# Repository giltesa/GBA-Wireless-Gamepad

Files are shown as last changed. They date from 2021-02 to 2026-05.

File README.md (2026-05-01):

# Game Boy Advance: Bluetooth HID Gamepad

### DESCRIPTION
This simple circuit allows you to connect an **ESP32** to the Link Cable port of the **Game Boy Advance** or **Game Boy Advance SP**, giving it **bluetooth** connectivity and turning it into a Human Interface Device (**HID**) so it can be used as a **bluetooth gamepad** and connected to a computer or phone to control games from the GBA.

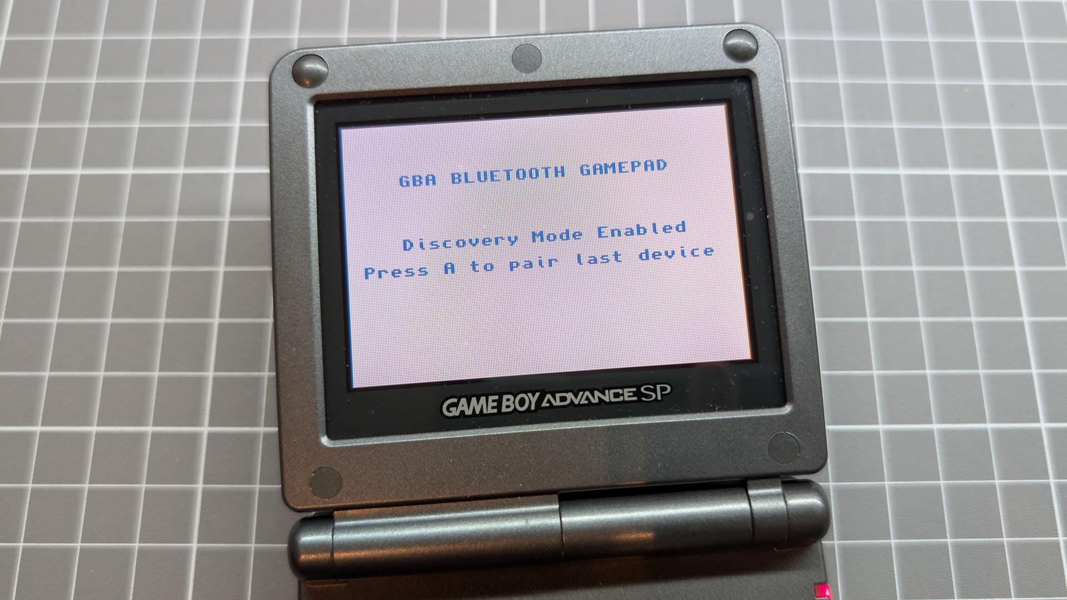
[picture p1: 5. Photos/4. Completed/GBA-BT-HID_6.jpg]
GBA-BT-HID_6


### REQUIRED
*   1x Game Boy Advance Wireless Adapter (shell & connector)
*   1x PCB (Download the Gerber files and order it yourself, PCB Thickness: 1mm)
*   1x ESP-WROOM-32 ESP32-WROOM-NARROW
*   1x Resistor 0603 1K
*   2x Resistor 0603 10K
*   1x LED 0603
*   2x Switch bottom 4.6\*2.8mm
*   1x USB UART-CP2102 **(1)**

**(1)** This [USB UART adapter](https://www.aliexpress.com/item/1005009534233685.html) can be connected directly to the board without the need for cables or soldering. Just connect it and keep both boards at a 45-degree angle so all the pins make electrical contact. Hold them together with a rubber band and, after programming the code, disconnect the boards.

### NOTES
I had a lot of difficulties in 2020 trying to flash the code onto the ESP32, and I eventually gave up without succeeding. Now, in 2026, I gave it another try and finally managed to do it, but it is still quite complicated for anyone not familiar with ESP32 development tools.

**Shyri Villar**’s code needs to be compiled to generate the .bin file, and once you have it, it must be flashed onto the ESP32. To simplify the process, I uploaded the already compiled .bin file to my repository, so the only remaining step is flashing it onto the ESP32. I also uploaded instructions to help with that task.

### ATTRIBUTIONS
The original idea is not mine, but [**Shyri Villar**](https://github.com/Shyri)’s, who designed it for a GBA to NGC cable and developed the software. I only adapted it to work with the GBA wireless adapter.

### LICENSE
This project is licensed under a **Creative Commons** license:
**[Attribution-NonCommercial-ShareAlike 4.0 International (CC BY-NC-SA 4.0) ](https://creativecommons.org/licenses/by-nc-sa/4.0/)**

Check the [LICENSE.md](LICENSE.md) for more information.

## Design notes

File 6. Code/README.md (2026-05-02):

# Flashing the ESP32 Firmware

This project includes precompiled ESP32 firmware binaries, so you do **not** need to compile anything yourself.

# Requirements

## Hardware

- ESP32 board
- USB cable
- Windows PC

## Files included

```text
flash_esp32.bat
bootloader.bin
gba-bt-hid-fw-esp32.bin
partitions_singleapp.bin
```

---

# Method 1 (Recommended) — Automatic Flash Tool

This is the easiest method.

## Step 1 — Install Python

Download and install Python:

https://www.python.org/downloads/windows/

IMPORTANT:

During installation, enable:

```text
Add Python to PATH
```

---

## Step 2 — Install esptool

Open PowerShell and run:

```powershell
py -m pip install esptool
```

---

## Step 3 — Connect the ESP32

Connect the ESP32 board to your PC using USB.

Wait a few seconds for Windows to detect it.

---

## Step 4 — Run the Flash Tool

Open the folder:

```text
6. Code
```

Double-click:

```text
flash_esp32.bat
```

The tool will display available COM ports, for example:

```text
Available COM ports:

  [1] COM3 - Silicon Labs CP210x USB to UART Bridge
  [2] COM5 - USB Serial Device
```

Type the number corresponding to your ESP32 and press ENTER.

Example:

```text
1
```

The firmware will then be flashed automatically.

---

# Method 2 — Manual Flashing

If the batch file does not work, you can flash manually.

Open PowerShell inside the `6. Code` folder and run:

```powershell
py -m esptool --chip esp32 --port COM3 --baud 115200 write_flash -z ^
0x1000 bootloader.bin ^
0x8000 partitions_singleapp.bin ^
0x10000 gba-bt-hid-fw-esp32.bin
```

Replace:

```text
COM3
```

with your actual ESP32 COM port.

---

# How to Find the Correct COM Port

## Option 1 — Device Manager

Open:

```text
Device Manager → Ports (COM & LPT)
```

Example:

```text
Silicon Labs CP210x USB to UART Bridge (COM3)
```

Your port is:

```text
COM3
```

---

# Flash Successful

If flashing completes correctly, you should see:

```text
Hash of data verified.
Leaving...
Hard resetting via RTS pin...
```

The ESP32 firmware is now installed and ready to use.

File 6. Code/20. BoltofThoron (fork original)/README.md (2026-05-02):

## GBA as Bluetooth Gamepad ##
Turn your Game Boy Advance into a Bluetooth Controller :)
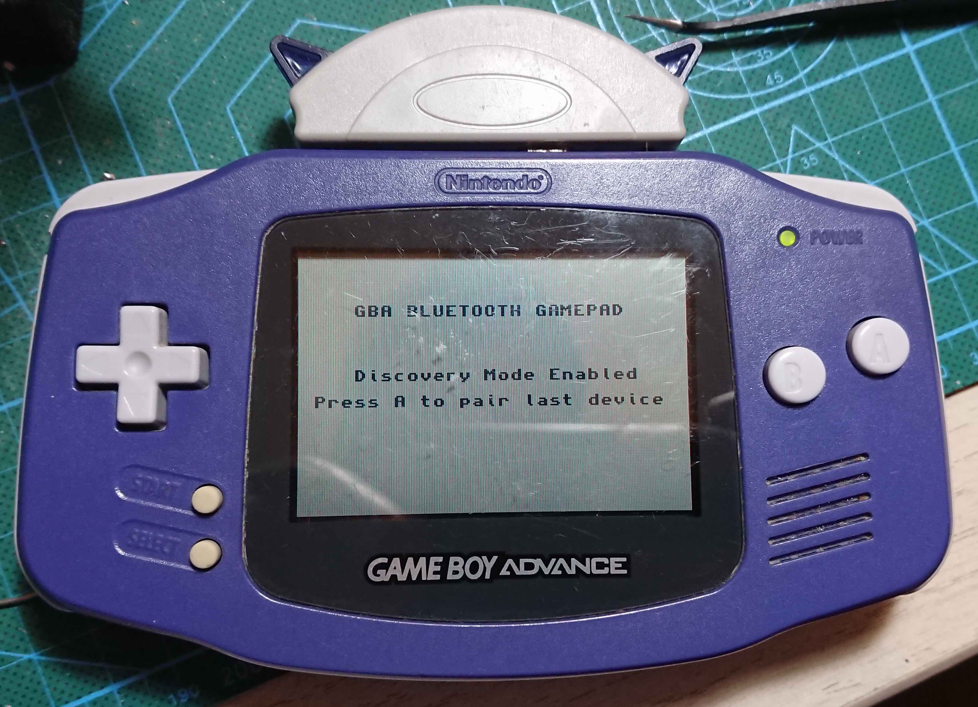
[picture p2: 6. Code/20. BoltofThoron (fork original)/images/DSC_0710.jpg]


### How to use it: ###
After launching the rom the bluetooth module enters discoverable mode. This means you can pair to it from whatever device you are going to use it with (PC, phone, Android TV...). After pairing the program will start sending keys to the device. The device address is stored so next time you launch you just have to press A to automatically connect to that device.

### How it works: ###
The project is basically an ESP32 connected to the GBA through the link port. With the device connected and without any cartridge inserted in the GBA, once the GBA turns on the ESP32 sends a small rom to be loaded in the GBA. This rom is a program made to enable communication between the ESP32 and GBA for both handling bluetooth conneciton and sending the user input to the ESP32 when it is connected to a bluetooth host and act as a gamepad. Unfortunatelly it only works with traditional GBA as I couln't make it work with GBA SP. This project supports the AGB-001 GBA, AGS-101 GBA SP, and DOL-017 GameCube Game Boy Player models. The AGS-001 GBA SP and OXY-001 Game Boy Micro are untested but should also work (Micro will require an EXT adapter).

When turned on the ESP32 (using the code found in [esp32](esp32) peforms a multiboot sequence through the SPI to the GBA sending a rom that the ESP32 has stored in the flash memory. The code for this rom can be found in [gba](gba). Once loaded the ESP32 enables the UART port in the same pins and the rom communicates with the ESP32 using UART through the link port.

This project was tested with ESP-IDF v3.3.2 that you can find here:

https://github.com/espressif/esp-idf/releases

You also will need to install btstack. Commit https://github.com/bluekitchen/btstack/commit/a0a4507b35ea396d076a62a67efb1a5a800c5ff9 is the most recent version that is proved to work in this project.

Just follow the ESP32 environment instructions here: https://docs.espressif.com/projects/esp-idf/en/v3.3.2/get-started/index.html

The ESP32 is powered by the 3.3V the GBA gives through the port.
Once the ESP32 is programmed the male link port connector should be wired to it like the following diagram:
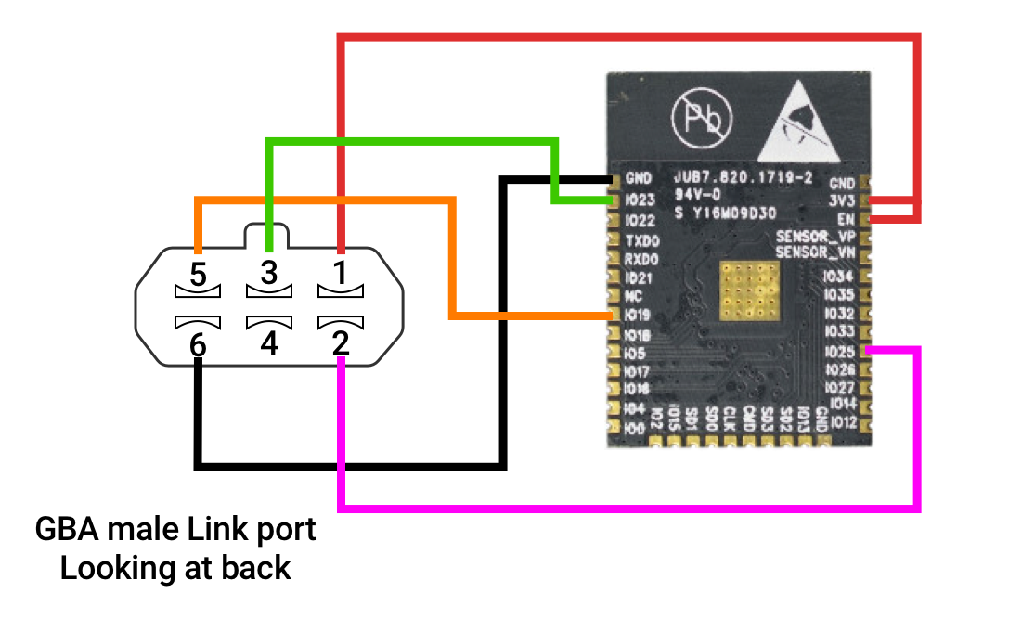
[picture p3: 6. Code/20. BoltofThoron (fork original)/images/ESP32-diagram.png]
ESP32Diagram Diagram


The first prototype was made with an Atmega and HC-05:
### Old version prototype: ###
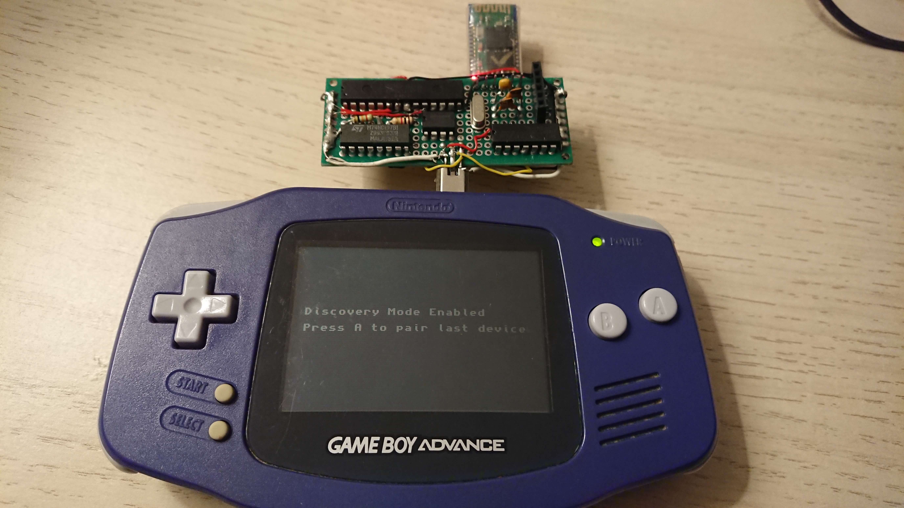
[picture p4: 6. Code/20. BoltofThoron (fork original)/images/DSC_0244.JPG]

The [gba](gba) contains the code for a GBA program that uses the link port to communicate with a HC-05 bluetooth module using UART (HC-05 flashed with RN-42 firmware, find how to do it in the links at the bottom).

This rom is stored in a W25Q32 flash chip. An Atmega328P performs a multiboot sequence reading from this chip and sending to the GBA through the link port. You can find the Atmega code [here](arduino) (It is actually written for arduino so you'll need to burn arduino's bootloader if you want to use it).

Once multiboot ends, the gba program runs and talks to the HC-05 to handle bluetooth connection, and key presses.

Additional 74XX157 quad 2-input multiplexer makes possible to multiplex SPI to read from the flash chip and send the multiboot, it alternates byte reads from the flash chip and send them to the GBA. Then using hcf4066 switch link port pins are switched from the spi to the HC-05 uart pins.

The whole circuit runs at 3.3V provided by GBA through the link port.

Final version of the circuit includes a 6 pin port that allows to reprogram the atmega if necessary. Also it lets to turn the atmega into a special write mode to reprogram the flash memory. You can find the code for the memory programmer [here](arduino-rom-flasher) it needs to run in a separate board (not arduino due to the large size of the rom to program, I used a Stellaris Launchpad)

There's a KiCad project [here](circuit) that includes this diagram:
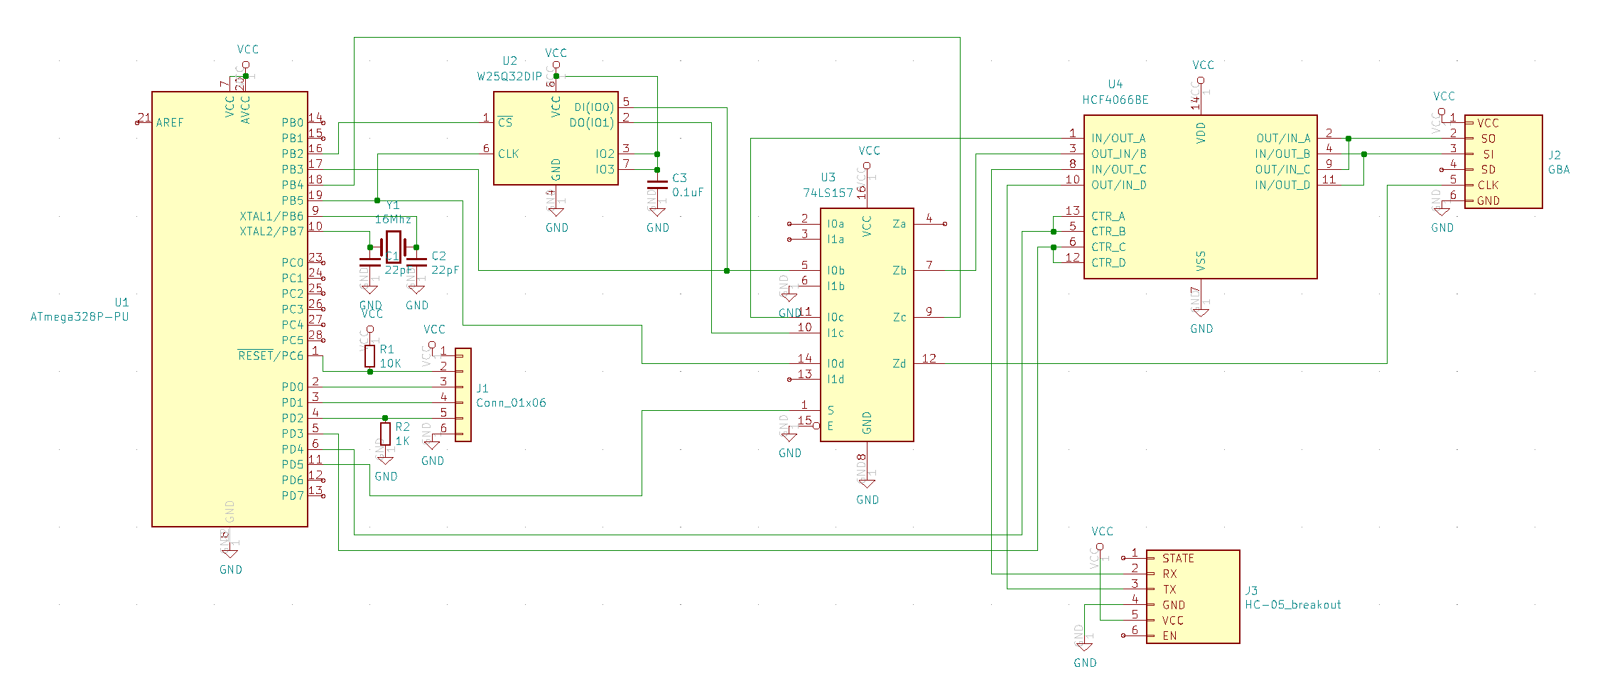
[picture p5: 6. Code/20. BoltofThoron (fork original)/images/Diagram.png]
Diagram GBA


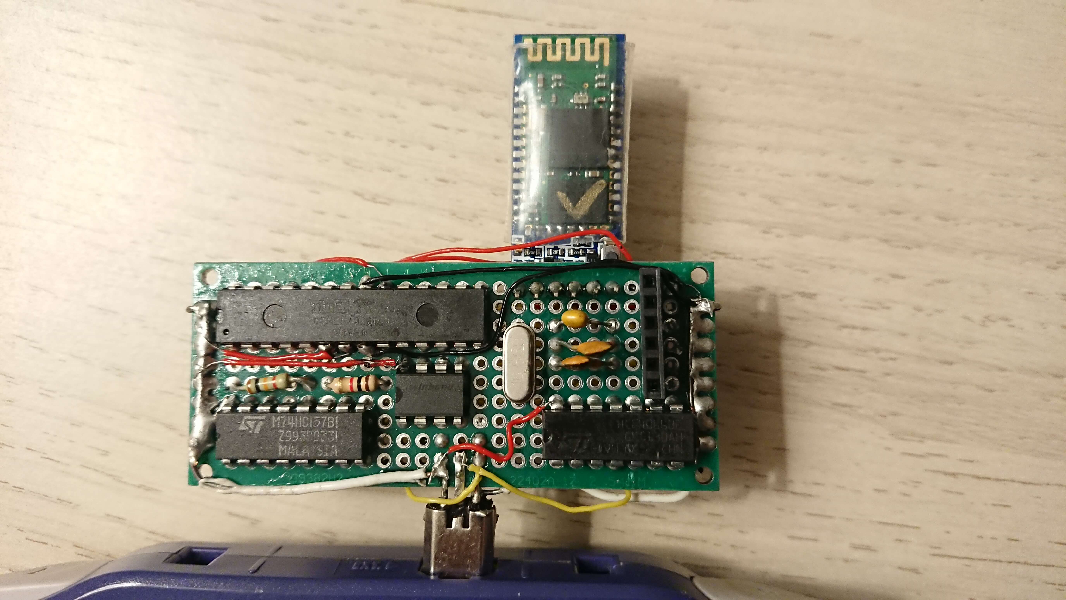
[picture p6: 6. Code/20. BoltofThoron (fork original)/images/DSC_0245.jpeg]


### Links that helped me to get this done: ###
ESP32 as a bluetooth Gamepad:
Thanks to the Bluecubemod from Nathan Reeves I learned how to turn ESP32 into a bluetooth gamepad
https://github.com/NathanReeves/BlueCubeMod

HC-05 as bluetooth HID device:

https://www.youtube.com/watch?v=y8PcNbAA6AQ

https://www.youtube.com/watch?v=BBqsVKMYz1I

GBA Multiboot:

http://www.akkit.org/info/gbatek.htm

https://github.com/akkera102/gba_01_multiboot

https://github.com/ataulien/elm-gba-multiboot

https://github.com/cartr/MSMCcable

https://github.com/tangrs/usb-gba-multiboot

https://github.com/MerryMage/gba-multiboot

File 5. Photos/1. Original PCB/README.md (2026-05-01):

# Original PCB

This section shows the original Nintendo Game Boy Advance wireless controller PCB design.

These images are provided for reference and documentation purposes.

## Gallery

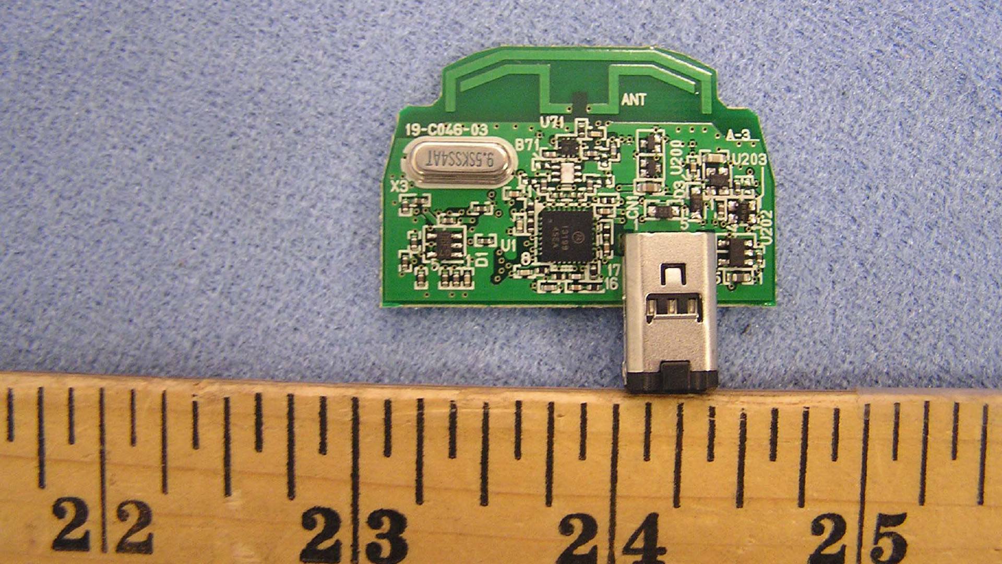
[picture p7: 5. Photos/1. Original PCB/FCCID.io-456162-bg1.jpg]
FCCID.io-456162-bg1

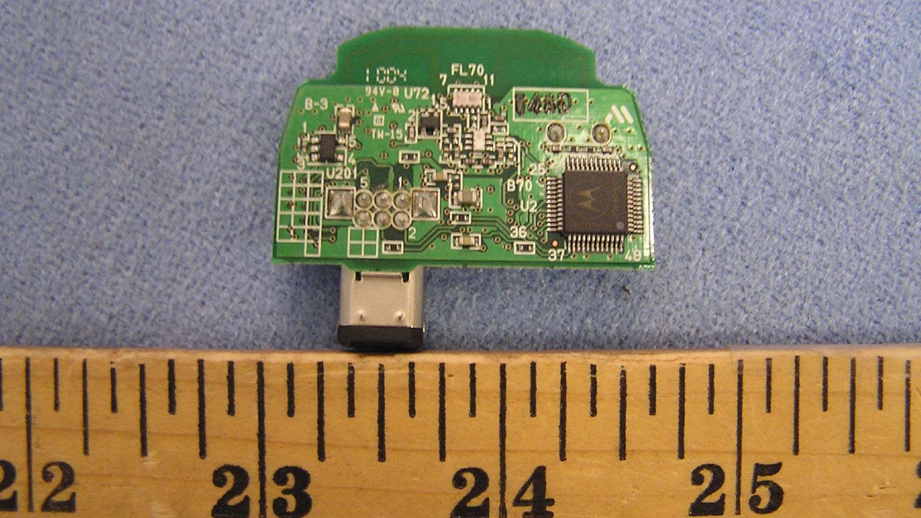
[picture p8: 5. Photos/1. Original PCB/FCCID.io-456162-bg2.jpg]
FCCID.io-456162-bg2

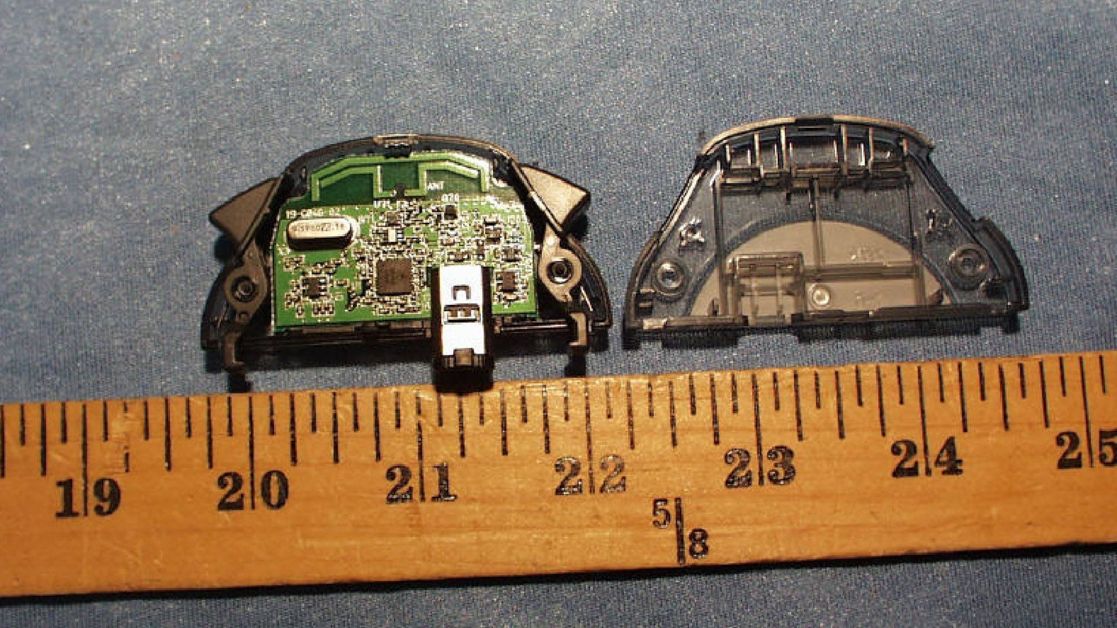
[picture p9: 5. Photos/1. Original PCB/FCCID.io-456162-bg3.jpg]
FCCID.io-456162-bg3

P1170439
P1170443
P1170444

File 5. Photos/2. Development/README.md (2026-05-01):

# Development

This section shows images from the development process of the GBA Wireless Gamepad PCB.

These photos document different stages of prototyping, and testing.

## Gallery



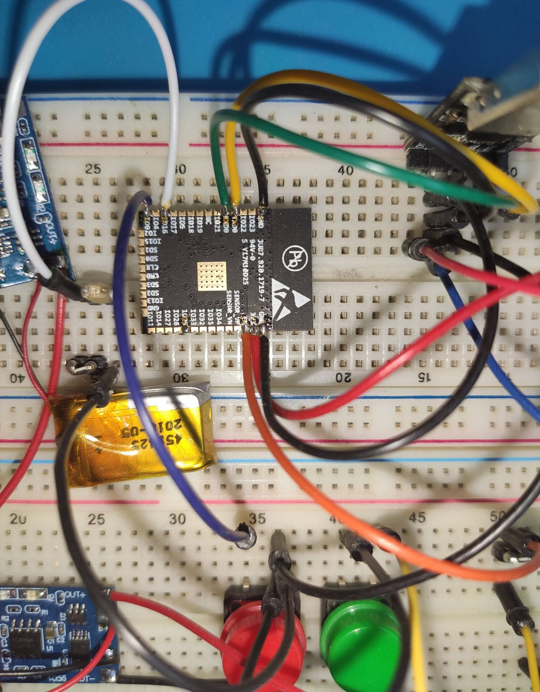
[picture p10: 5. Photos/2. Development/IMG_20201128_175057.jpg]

P1170456
P1170457
P1170461

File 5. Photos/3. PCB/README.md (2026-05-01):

# PCB (Assembled Board)

This section shows the manufactured and fully assembled PCB of the GBA Wireless Gamepad.

These images document the final hardware build, including soldering and component placement.

## Gallery

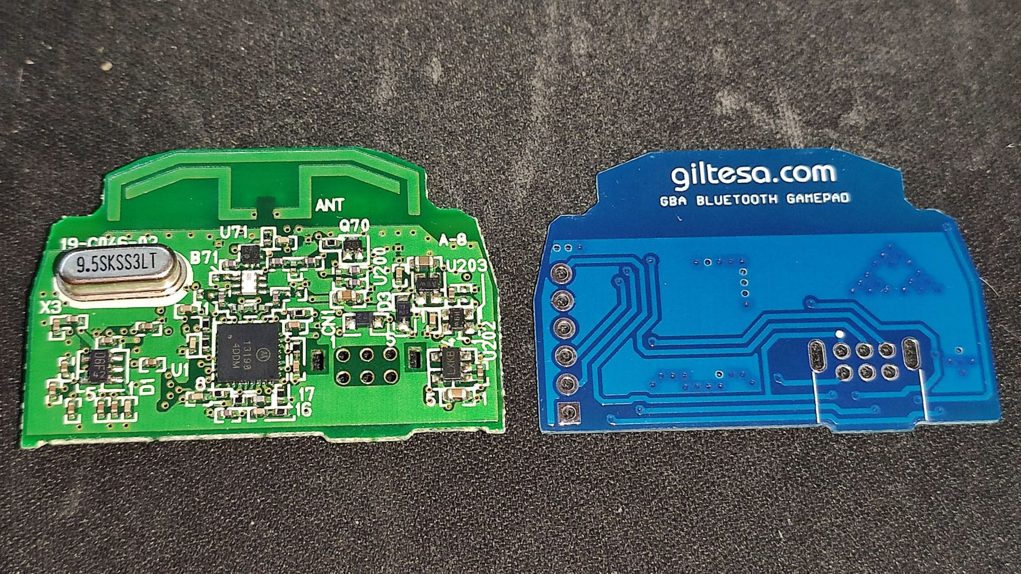
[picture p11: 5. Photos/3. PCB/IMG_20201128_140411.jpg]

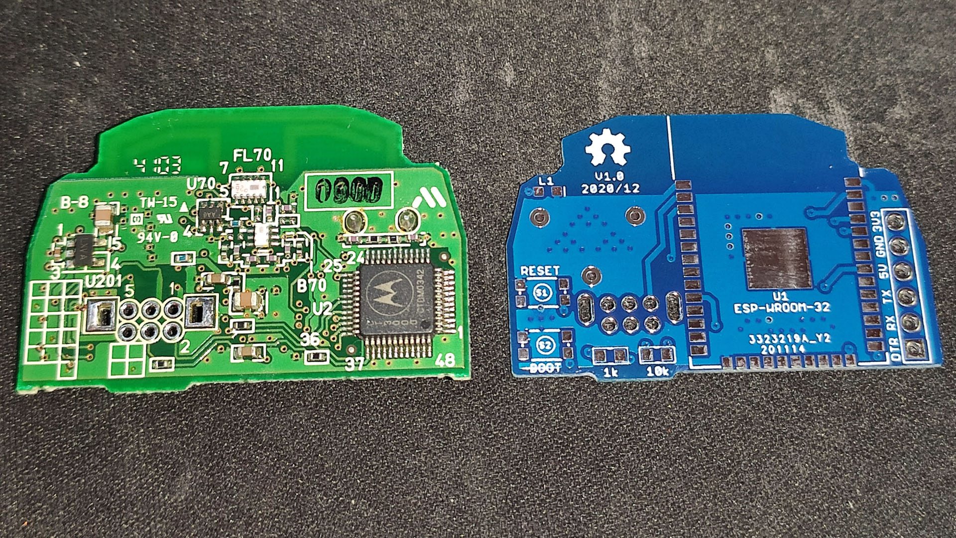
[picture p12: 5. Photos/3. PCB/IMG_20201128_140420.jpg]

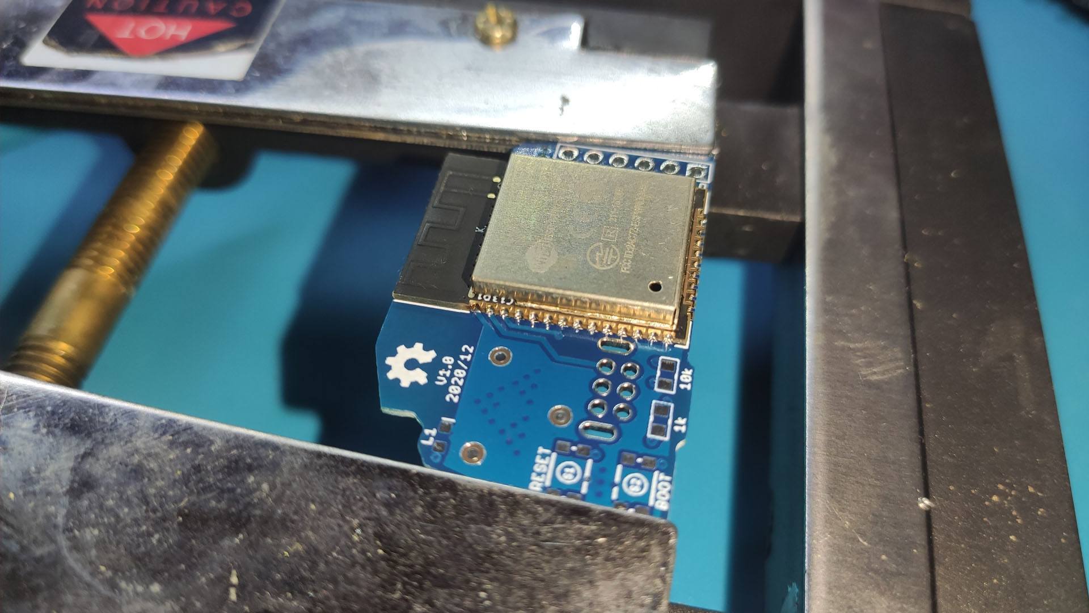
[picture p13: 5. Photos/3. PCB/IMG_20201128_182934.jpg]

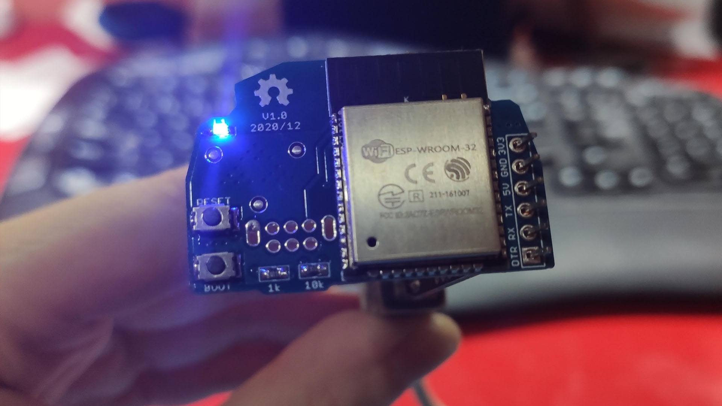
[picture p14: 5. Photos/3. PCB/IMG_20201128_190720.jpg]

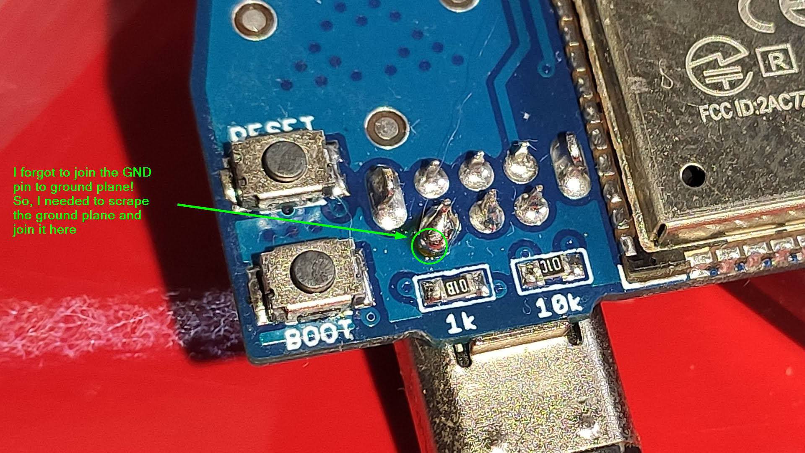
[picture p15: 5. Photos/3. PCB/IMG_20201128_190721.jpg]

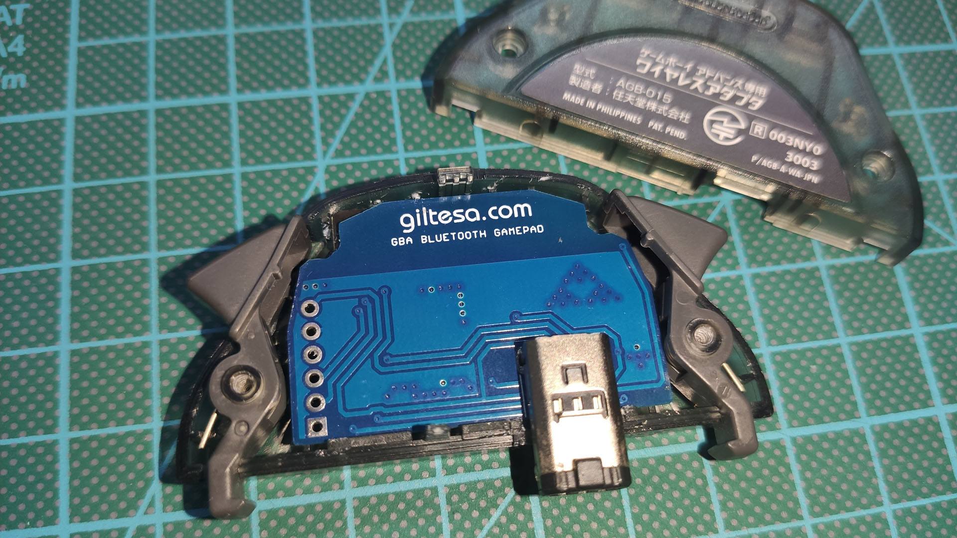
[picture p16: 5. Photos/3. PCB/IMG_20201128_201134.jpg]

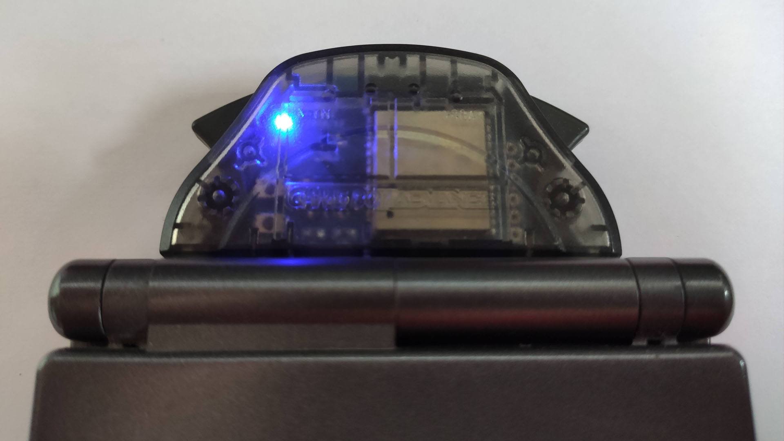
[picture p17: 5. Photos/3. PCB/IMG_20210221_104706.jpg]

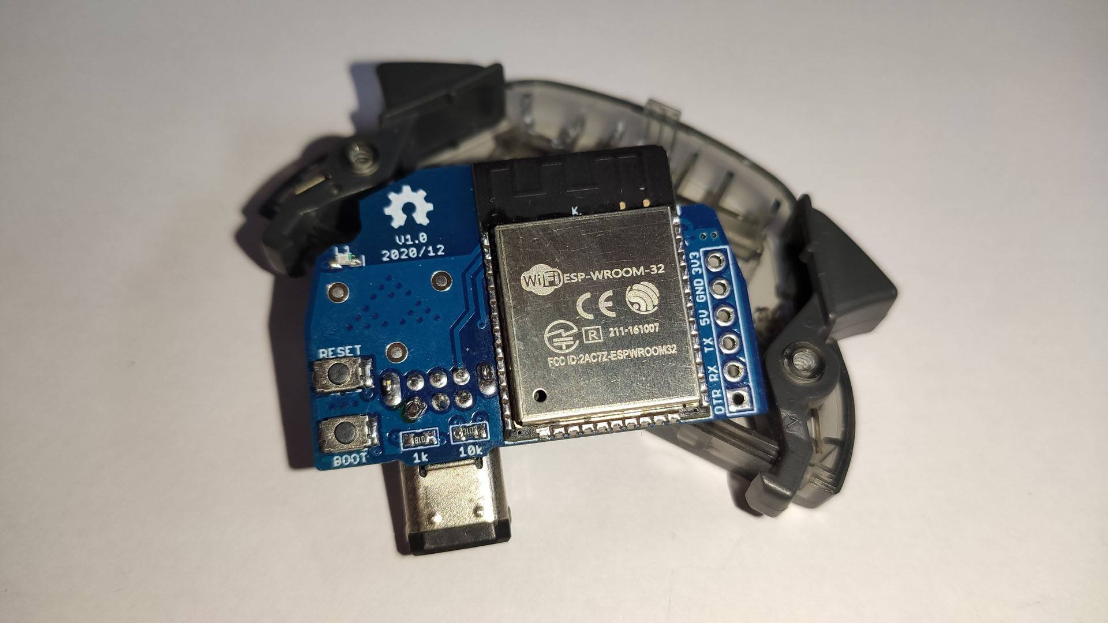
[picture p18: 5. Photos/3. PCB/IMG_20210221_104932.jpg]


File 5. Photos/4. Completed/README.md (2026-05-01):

# Completed Build

This section shows the final assembled GBA Wireless Gamepad.

## Gallery

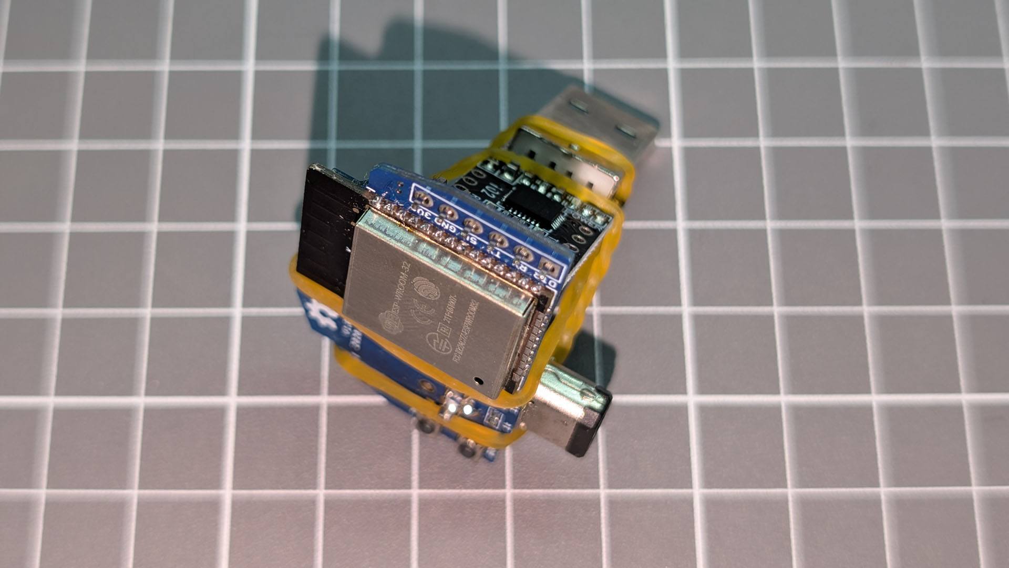
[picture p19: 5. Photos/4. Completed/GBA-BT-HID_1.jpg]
GBA-BT-HID_1

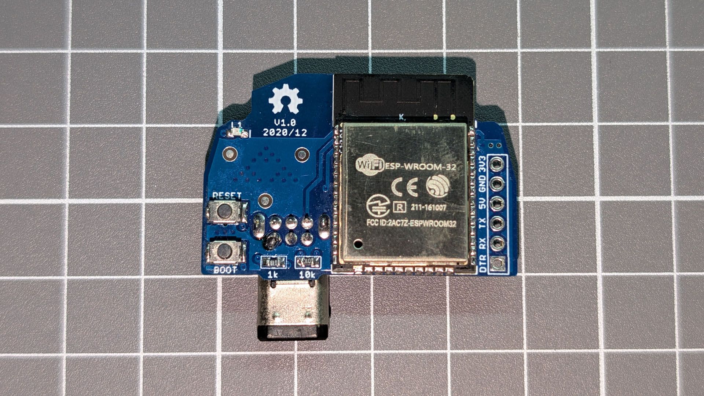
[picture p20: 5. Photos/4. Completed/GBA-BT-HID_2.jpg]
GBA-BT-HID_2

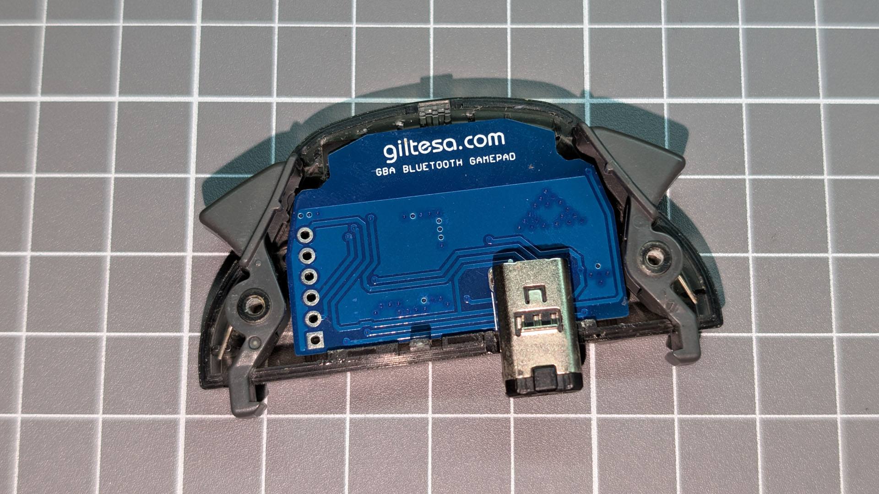
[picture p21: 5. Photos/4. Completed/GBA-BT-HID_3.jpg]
GBA-BT-HID_3

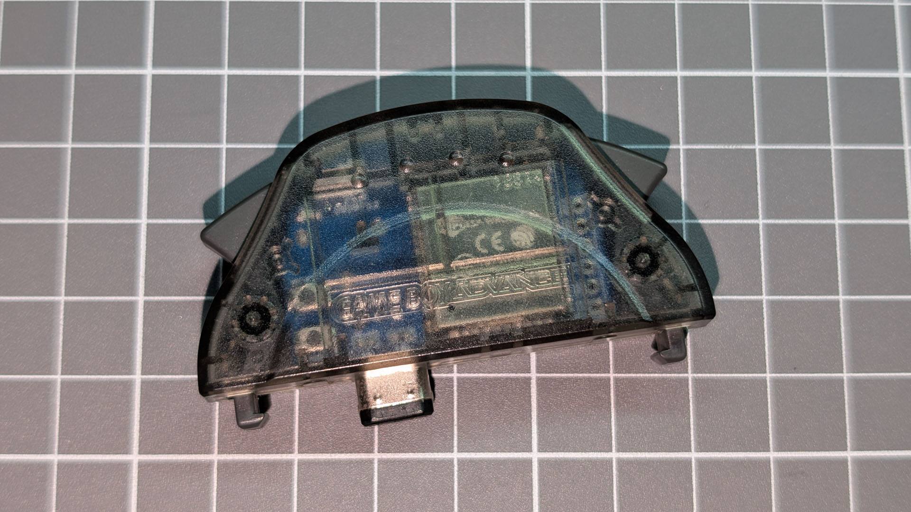
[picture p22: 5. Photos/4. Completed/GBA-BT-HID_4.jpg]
GBA-BT-HID_4

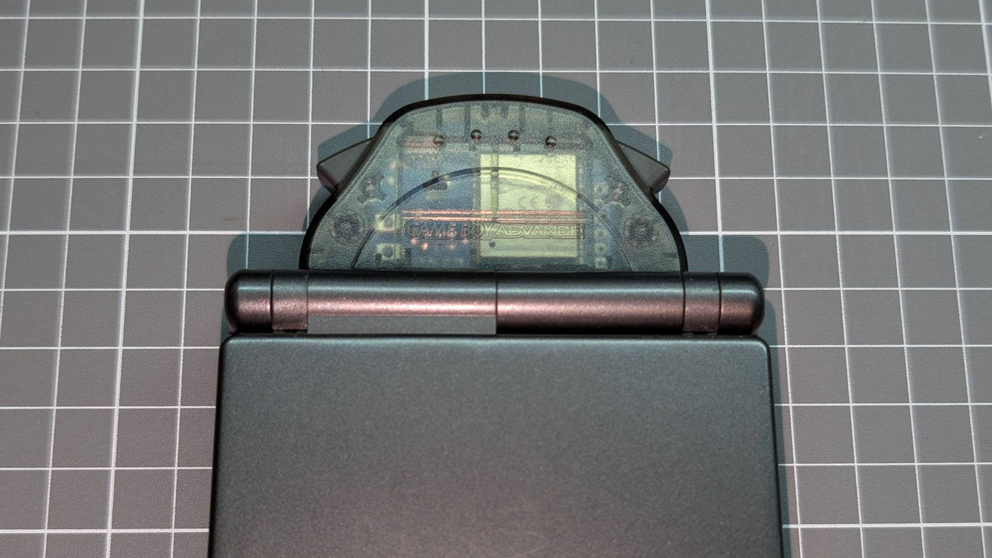
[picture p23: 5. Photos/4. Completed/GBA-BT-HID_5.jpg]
GBA-BT-HID_5

GBA-BT-HID_6
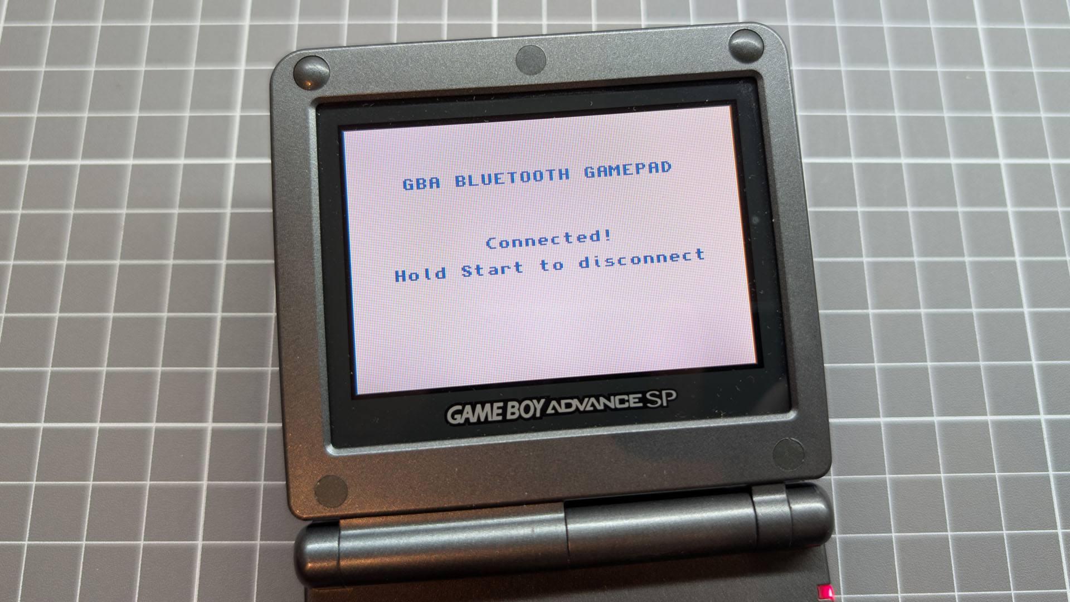
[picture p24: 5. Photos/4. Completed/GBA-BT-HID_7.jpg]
GBA-BT-HID_7


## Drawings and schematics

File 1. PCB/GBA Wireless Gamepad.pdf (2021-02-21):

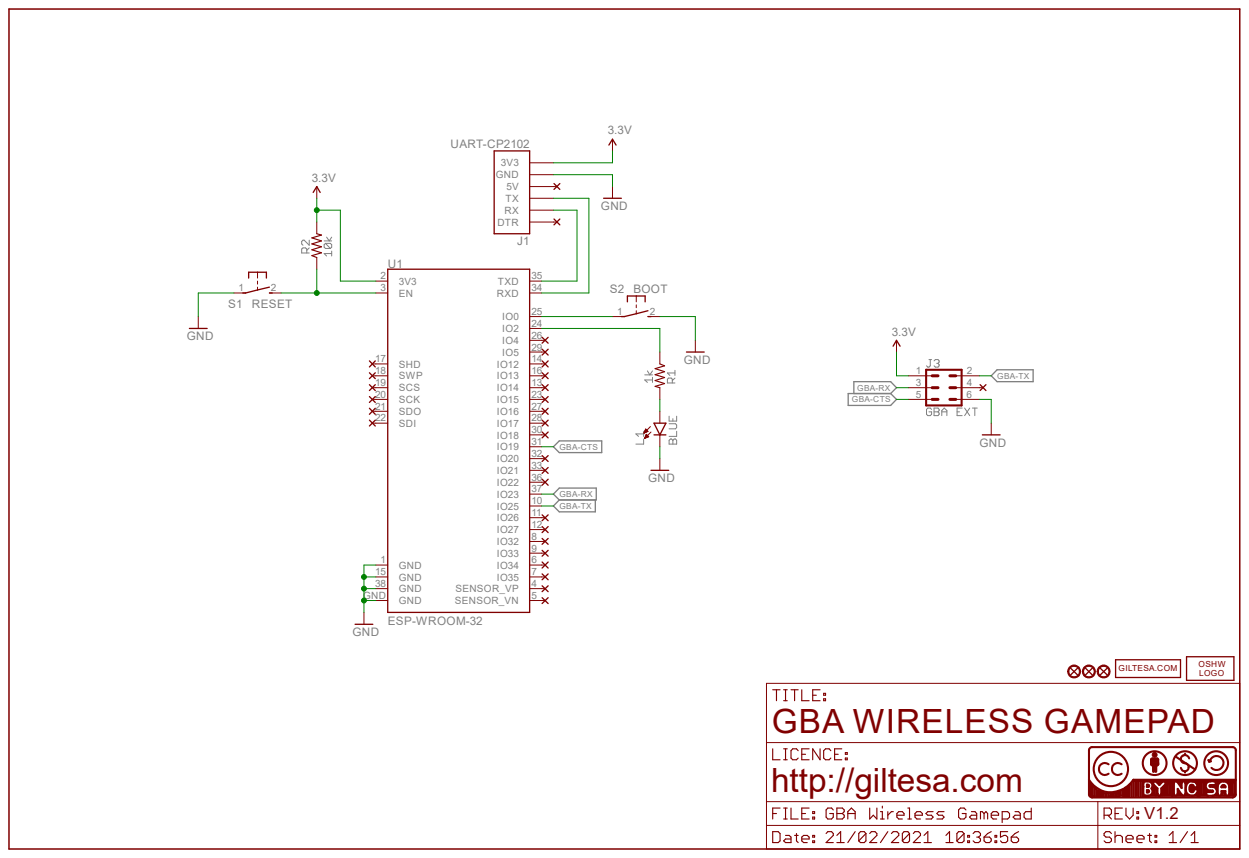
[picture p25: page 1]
ESP-WROOM-32; GND; UART-CP2102; RESET; BOOT; GND GND; GND 1 GND 15 GND 38; RXD; SCK 20; SCS 19; SDI 22; SDO 21; SENSOR_VN; 5 SENSOR_VP; SHD 17 SWP 18; TXD; DTR; 3V3 GND; GBA-RX; GBA-CTS; GBA-TX; GBA WIRELESS GAMEPAD; GILTESA.COM; OSHW; LOGO

http://giltesa.com

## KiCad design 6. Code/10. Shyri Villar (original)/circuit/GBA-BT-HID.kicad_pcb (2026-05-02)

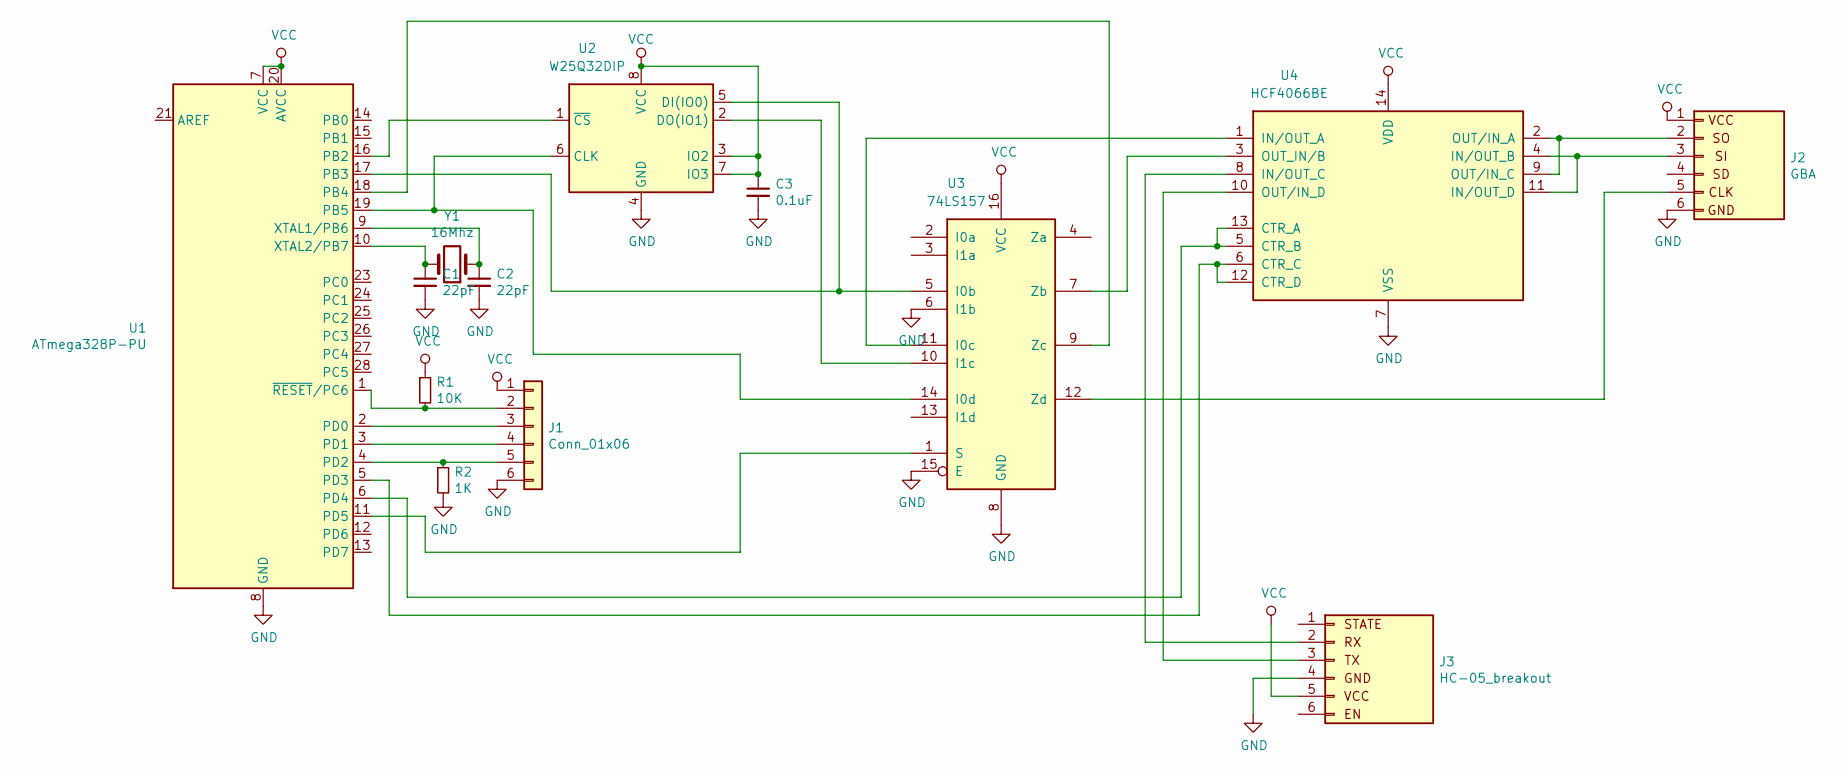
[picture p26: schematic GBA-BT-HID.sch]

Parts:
C1, C2: 22pF; C_Disc_D4.7mm_W2.5mm_P5.00mm
C3: 0.1uF; C_Disc_D4.7mm_W2.5mm_P5.00mm
J1: Conn_01x06; PinSocket_1x06_P2.00mm_Vertical
J2: GBA; PinSocket_1x06_P2.00mm_Vertical
J3: HC-05_breakout
R1: 10K; R_Axial_DIN0207_L6.3mm_D2.5mm_P10.16mm_Horizontal
R2: 1K; R_Axial_DIN0207_L6.3mm_D2.5mm_P10.16mm_Horizontal
U1: ATmega328P-PU; DIP-28_W7.62mm
U2: W25Q32DIP; DIP-8_W7.62mm
U3: 74LS157; DIP-16_W7.62mm
U4: HCF4066BE; DIP-14_W7.62mm
Y1: 16Mhz; Resonator-2Pin_W10.0mm_H5.0mm

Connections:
GND: C1.2, C2.2, C3.2, J1.6, J2.6 (GND), J3.4, R2.2, U1.8 (GND), U1.22 (GND), U2.4 (GND), U3.6 (I1b), U3.8 (GND), U3.15 (E), U4.7 (VSS)
unnamed: C1.1, U1.10 (XTAL2/PB7), Y1.2
unnamed: C2.1, U1.9 (XTAL1/PB6), Y1.1
unnamed: J1.2, R1.2, U1.1 (~RESET~/PC6)
unnamed: J1.3, U1.2 (PD0)
unnamed: J1.4, U1.3 (PD1)
unnamed: J1.5, R2.1, U1.4 (PD2)
unnamed: J2.2 (SO), U4.2 (OUT/IN_A), U4.9 (OUT/IN_C)
unnamed: J2.3 (SI), U4.4 (IN/OUT_B), U4.11 (IN/OUT_D)
unnamed: J2.5 (SC), U3.12 (Zd)
unnamed: J3.2, U4.8 (IN/OUT_C)
unnamed: J3.3, U4.10 (OUT/IN_D)
unnamed: U1.5 (PD3), U4.6 (CTR_C), U4.12 (CTR_D)
unnamed: U1.6 (PD4), U4.5 (CTR_B), U4.13 (CTR_A)
unnamed: U1.11 (PD5), U3.1 (S)
unnamed: U1.16 (PB2), U2.1 (~CS)
unnamed: U1.17 (PB3), U2.5 (DI(IO0)), U3.5 (I0b)
unnamed: U1.18 (PB4), U3.9 (Zc)
unnamed: U1.19 (PB5), U2.6 (CLK), U3.14 (I0d)
unnamed: U2.2 (DO(IO1)), U3.10 (I1c)
unnamed: U3.7 (Zb), U4.3 (OUT_IN/B)
unnamed: U3.11 (I0c), U4.1 (IN/OUT_A)
VCC: C3.1, J1.1, J2.1 (Vcc), J3.5, R1.1, U1.7 (VCC), U1.20 (AVCC), U2.3 (IO2), U2.7 (IO3), U2.8 (VCC), U3.16 (VCC), U4.14 (VDD)

Board: 2 copper layers, 13 parts (0 on the bottom side), 23 nets, no tracks yet.

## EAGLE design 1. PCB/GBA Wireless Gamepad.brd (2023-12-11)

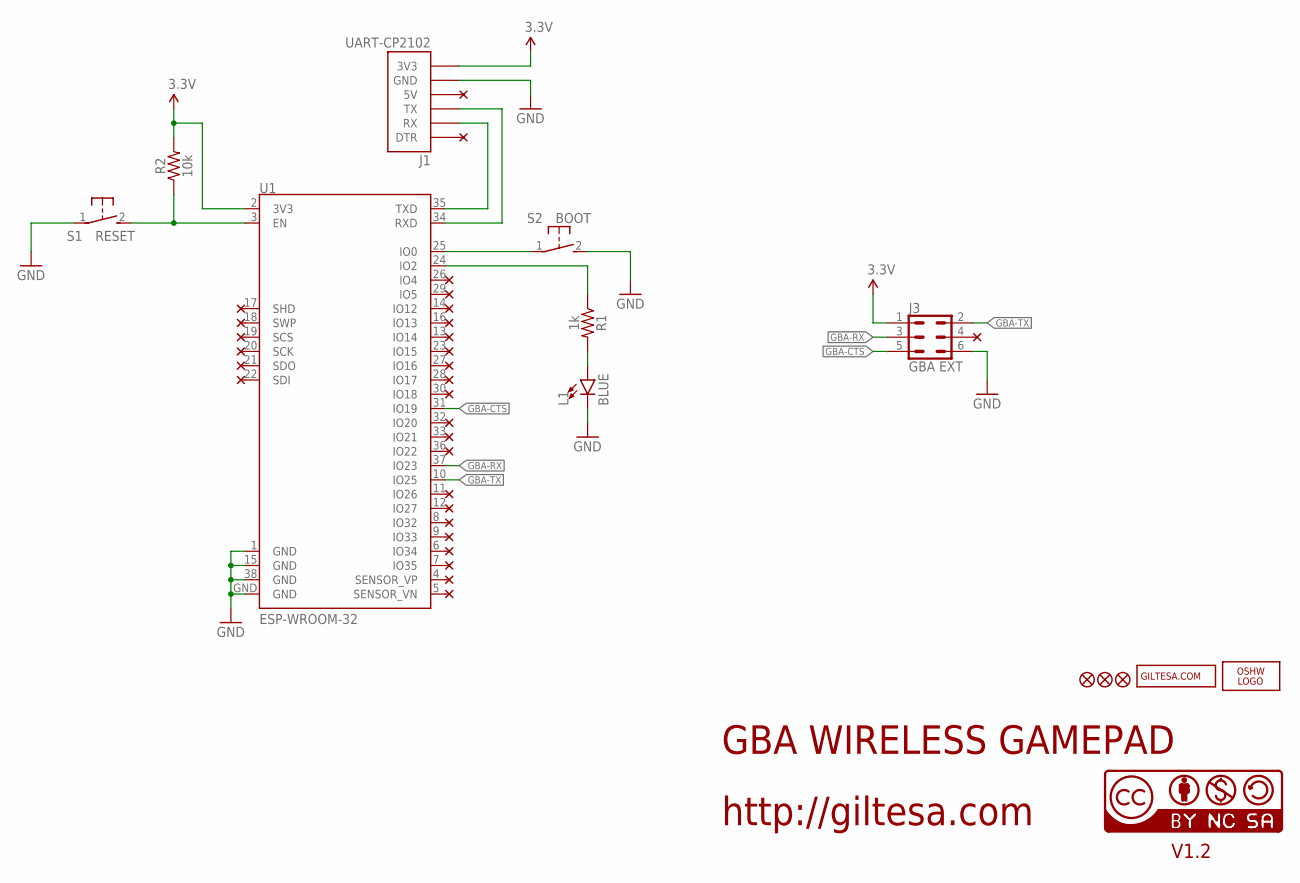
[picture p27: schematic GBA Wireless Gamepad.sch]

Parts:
J1: UART-CP2102
J3: GBA EXT; GBA_EXT
L1: BLUE; LED-0603
LOGO1: OSHW_LOGO_FILLX0150-NT; OSHW_FILLX150_NOTEXT
R1: 1k; R0603
R2: 10k; R0603
S1: RESET; SWITCH_SMD_4.6X2.8MM
S2: BOOT; SWITCH_SMD_4.6X2.8MM
U1: ESP-WROOM-32; ESP32-WROOM-NARROW
U$6, U$7, U$14: FIDUCIAL1X2; FIDUCIAL-1X2
U$10: GILTESA.COM_MASK; GILTESA.COM_MASK_15MM
U$17: CC-NC-BCNIX; CC-NC-B_NIX

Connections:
3.3V: J1.3V3, J3.1, R2.2, U1.2 (3V3)
CHIP_PU: R2.1, S1.2 (B), U1.3 (EN)
GBA-CTS: J3.5, U1.31 (IO19)
GBA-RX: J3.3, U1.37 (IO23)
GBA-TX: J3.2, U1.10 (IO25)
GND: J1.GND, J3.6, L1.C, S1.1 (A), S2.2 (B), U1.1 (GND), U1.15 (GND), U1.38 (GND), U1.GND
unnamed: S2.1 (A), U1.25 (IO0)
unnamed: L1.A, R1.2
unnamed: R1.1, U1.24 (IO2)
RX: J1.TX, U1.34 (RXD)
TX: J1.RX, U1.35 (TXD)

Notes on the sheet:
GBA WIRELESS GAMEPAD
http://giltesa.com
V1.2

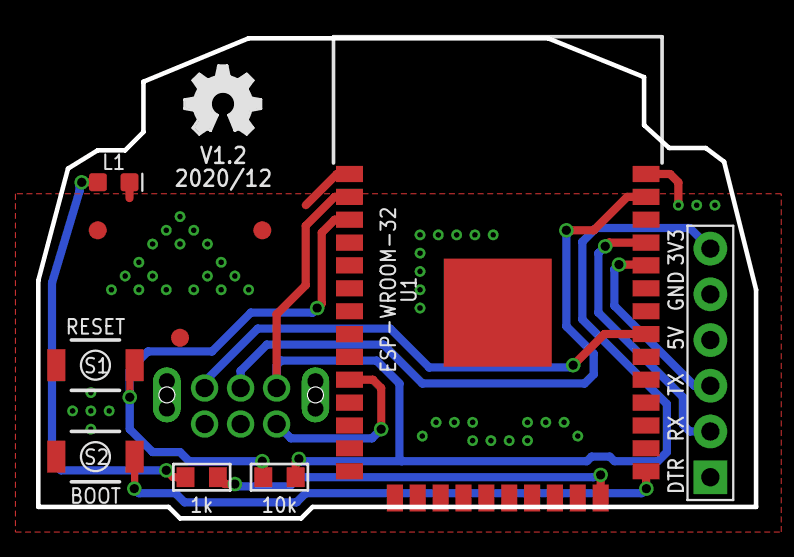
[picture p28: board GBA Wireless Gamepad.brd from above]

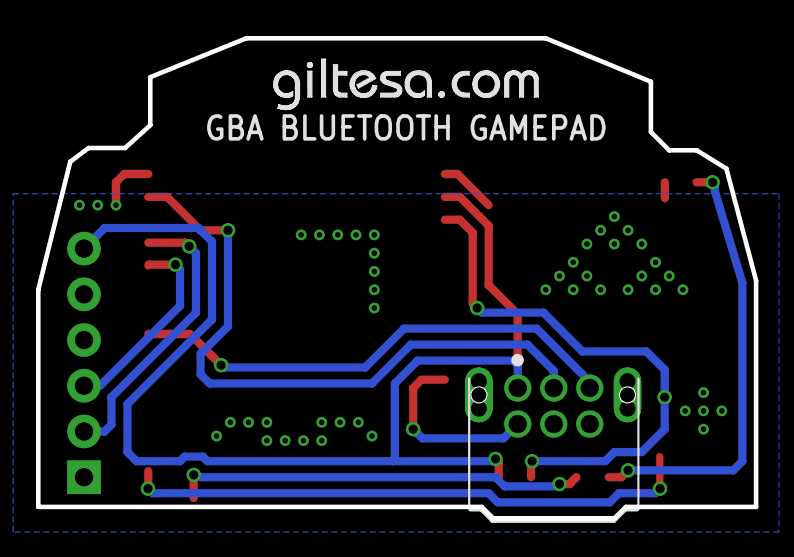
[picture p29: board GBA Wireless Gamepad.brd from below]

Board: 2 copper layers, 39.9 x 26.7 mm, 14 parts (2 on the bottom side), 11 nets.

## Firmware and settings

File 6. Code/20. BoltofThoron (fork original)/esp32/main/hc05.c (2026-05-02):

//
// Created by Shyri
// Simulates a subset of HC-05 Bluetooth module commands and operations
//
#include "hc05.h"

#include "btstack.h"
#include "btstack_event.h"
#include "btstack_stdin.h"

#include "freertos/FreeRTOS.h"
#include "freertos/task.h"
#include "freertos/queue.h"
#include "freertos/semphr.h"
#include "btstack_run_loop_freertos.h"
#include "driver/gpio.h"

#define DEVICE_NAME "GBA Bluetooth"

#define COM_MODE_REQUEST "$$$"
#define COM_MODE_RESPONSE "CMD"
#define AUTOCONNECT_REQUEST "CFR"
#define CONNECTED_RESULT "%CONNECT"


static bool inCommandMode = false;

typedef enum DESCRIPTOR_BUTTONS {
    DPAD_N = 0x00,
    DPAD_NE = 0x01,
    DPAD_E = 0x02,
    DPAD_SE = 0x03,
    DPAD_S = 0x04,
    DPAD_SW = 0x05,
    DPAD_W = 0x06,
    DPAD_NW = 0x07,
    DPAD_RELEASED = 0x08,

    HID_KEY_A = 0x10,
    HID_KEY_B = 0x20,

    HID_KEY_R = 0x40,
    HID_KEY_L = 0x80,

    HID_KEY_START = 0x01,
    HID_KEY_SELECT = 0x02

} DESCRIPTOR_BUTTONS_BITS;

typedef enum HC05_BUTTONS {
    BUTTON_A = (1 << 0),
    BUTTON_B = (1 << 1),
    BUTTON_L = (1 << 4),
    BUTTON_R = (1 << 5),
    BUTTON_SELECT = (1 << 4),
    BUTTON_START = (1 << 5),
    PAD_DOWN = 0x7F,
    PAD_UP = 0x80,
    PAD_RIGHT = 0x7F,
    PAD_LEFT = 0x80
} HC05_BUTTONS_BITS;

const uint8_t hid_descriptor_gba[] = {
	// Gamepad 1 with DPAD and 8 buttons (2 unused) - 32 bits total
	0x05, 0x01,		// USAGE_PAGE (Generic Desktop)
	0x09, 0x05,		// USAGE (Gamepad)
	0xA1, 0x01,		// COLLECTION (Application)
		//Padding - 16 bits
		0x95, 0x02,		//     REPORT_COUNT = 3
        0x75, 0x08,		//     REPORT_SIZE = 8
        0x81, 0x03,		//     INPUT = Cnst,Var,Abs
		0xA1, 0x00,		//	 COLLECTION (Physical)
			// Buttons - 8 bits (Buttons X, Y are unused)
			0x05, 0x09,			//   USAGE_PAGE (Button)
			0x19, 0x01,			//   USAGE_MINIMUM (Button 1)
			0x29, 0x08,			//   USAGE_MAXIMUM (Button 8)
			0x15, 0x00,			//   LOGICAL_MINIMUM (0)
			0x25, 0x01,			//   LOGICAL_MAXIMUM (1)
			0x95, 0x08,			//   REPORT_COUNT (8)
			0x75, 0x01,			//   REPORT_SIZE (1)
			0x81, 0x02,			//   INPUT (Data,Var,Abs)
			// DPAD - 8 bits
			0x05, 0x01,			//	 USAGE_PAGE (Generic Desktop)
			0x09, 0x39,			//	 USAGE (Hat switch)
			0x15, 0x00,			//	 LOGICAL_MINIMUM (0)
			0x25, 0x07,			//	 LOGICAL_MAXIMUM (7)
			0x35, 0x00,			//	 PHYSICAL_MINIMUM (0)
			0x46, 0x3B, 0x01,	//	 PHYSICAL_MAXIMUM (315)
			0x65, 0x14,			//	 UNIT (Degrees)
			0x95, 0x01,			//	 REPORT_COUNT (1)
			0x75, 0x08,			//	 REPORT_SIZE (8)
			0x81, 0x42,			//	 INPUT (Data,Var,Abs,Null State)
		0xC0, 		// END_COLLECTION (Physical)		
	0xC0 		// END_COLLECTION (Application)
};


//								Input HID	Res.  Btn1	Btn2
static uint8_t send_report[] = {0xA1, 0x11, 0x00, 0x00, 0x08};

static uint8_t hid_service_buffer[400];
static uint8_t device_id_sdp_service_buffer[400];
static const char hid_device_name[] = DEVICE_NAME;
static uint16_t hid_cid = 0;

static uint8_t but1_send = 0;
static uint8_t but2_send = DPAD_RELEASED;

static bool connected = false;

static const TickType_t xDelay = 1000 / portTICK_PERIOD_MS;

static btstack_packet_callback_registration_t hci_event_callback_registration;

void interpretMessage(int length, char *message);

void initBluetooth();

void initStatusIndicator();

void updateStatusIndicator(uint32_t level);

void updateButtons(const char *message);

static void packet_handler(uint8_t packet_type, uint16_t channel, uint8_t *packet, uint16_t packet_size);

void connectLastDevice();

esp_err_t save_addr(bd_addr_t *addr);

esp_err_t read_addr(bd_addr_t *addr);


static void read_uart() {
    while (1) {
        checkHC05();
        vTaskDelay(2);
    }
}

static void update_led() {
	while (1) {
		if (connected && gpio_get_level(GPIO_NUM_2) == 0) {
			updateStatusIndicator(1);
		} else if (!connected) {
			updateStatusIndicator(1);
			vTaskDelay(xDelay);
			updateStatusIndicator(0);
			vTaskDelay(xDelay);
		}
		vTaskDelay(xDelay);
	}
}

void initHC05() {
	initStatusIndicator();
    initBluetooth();
    initUART();
    xTaskCreate(read_uart, "read_uart", 2048, NULL, 1, NULL);
	xTaskCreate(update_led, "update_led", 1024, NULL, 0, NULL);
}

void initBluetooth() {
    hci_event_callback_registration.callback = &packet_handler;
    hci_add_event_handler(&hci_event_callback_registration);
    hci_register_sco_packet_handler(&packet_handler);
    gap_discoverable_control(1);
    gap_set_class_of_device(0x2508);
    gap_set_local_name(DEVICE_NAME);

    l2cap_init();
    sdp_init();
    memset(hid_service_buffer, 0, sizeof(hid_service_buffer));
    hid_create_sdp_record(hid_service_buffer, 0x10001, 0x2508, 33, 0, 0, 0, hid_descriptor_gba,
                          sizeof(hid_descriptor_gba), hid_device_name);
    sdp_register_service(hid_service_buffer);
    device_id_create_sdp_record(device_id_sdp_service_buffer, 0x10003, DEVICE_ID_VENDOR_ID_SOURCE_BLUETOOTH,
                                BLUETOOTH_COMPANY_ID_BLUEKITCHEN_GMBH, 1, 1);
    sdp_register_service(device_id_sdp_service_buffer);
    hid_device_init(1, sizeof(hid_descriptor_gba), hid_descriptor_gba);
    hid_device_register_packet_handler(&packet_handler);

    hci_power_control(HCI_POWER_ON);
}

void initStatusIndicator() {
	gpio_config_t io_conf = {};
	
	io_conf.pin_bit_mask = (1ULL << GPIO_NUM_2);
	io_conf.mode = GPIO_MODE_OUTPUT;
	io_conf.pull_up_en = GPIO_PULLUP_DISABLE;
	io_conf.pull_down_en = GPIO_PULLDOWN_DISABLE;
	io_conf.intr_type = GPIO_INTR_DISABLE;
	
	gpio_config(&io_conf);
}

void checkHC05() {
    char message[50];
    int length = uartRead(message);

    if (length > 0) {
        interpretMessage(length, message);
    }
}

void interpretMessage(int length, char *message) {
    if (inCommandMode) {
        if (strncmp((const char *) message, AUTOCONNECT_REQUEST, length - 1) == 0) { // length-1 cause ending 0x0D
            inCommandMode = false;
            connectLastDevice();
        }
    } else {
        if (strncmp((const char *) message, COM_MODE_REQUEST, length) == 0) {
            inCommandMode = true;
            uartWrite(COM_MODE_RESPONSE);
        } else if (connected) {
            // Check headers
            if (message[0] == 0xFD && message[1] == 0x06) {
                // Get HC-05 buttons
                updateButtons(message);
            } else if (message[0] == 0x00 && message[1] == 0x0D) {
                // Disconnection requested
                hid_device_disconnect(hid_cid);
            }
        }
    }
}

void bin(unsigned n) { 
    unsigned i; 
    for (i = 1 << 7; i > 0; i = i / 2) 
        (n & i)? printf("1"): printf("0"); 
}
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

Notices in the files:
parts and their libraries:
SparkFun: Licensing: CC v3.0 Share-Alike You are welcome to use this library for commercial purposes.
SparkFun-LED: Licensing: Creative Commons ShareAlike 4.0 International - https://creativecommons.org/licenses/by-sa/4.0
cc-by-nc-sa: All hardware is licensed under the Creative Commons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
